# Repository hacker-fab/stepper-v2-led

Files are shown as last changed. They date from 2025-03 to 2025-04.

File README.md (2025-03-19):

# stepper-v2-led
Hacker Fab V2 Stepper UV LED PCB

UV LED module for the [Stepper V2](https://docs.hackerfab.org/home/fab-toolkit/patterning/lithography-stepper-v2-build-work-in-progress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)

Files imported from [Google drive](https://drive.google.com/drive/u/1/folders/1X3nmuruO58prPQBm8DrWUhfM-LNq0qWm)

Supported projectors:
  * DLPDLCR471TPEVM: the classic V2 projector
  * DLP4710EVM-LC: experimental projector due to part shortage

LED compatibility:

| Pin | DLPDLCR471TPEVM | DLP4710EVM-LC |
| --- | --- | --- |
| 10 | N/C | Common |
| 9 | N/C | Common |
| 8 | LED+ | Common |
| 7 | LED+ | Common |
| 6 | LED+ | Common |
| 5 | LED+ | LED1+ |
| 4 | LED- | LED1+ |
| 3 | LED- | LED1+ |
| 2 | LED- | LED2+ |
| 1 | LED- | LED2+ |

"You can order it through your PCB manufacturer of choice (we used JLCPCB). However, note that the PCB is copper core. This is because the LEDs draw several amps of current in operation. To ensure that the PCB doesn't melt, you should use copper core to facilitate better heat flow."

"When ordering the PCB, the manufacturer might send you an email asking about a missing heatsink file. In this case, please respond that this project does not include a direct heatsink, as the copper core PCB itself is designed to handle the thermal management."

DLPDLCR471TPEVM (4 LED) BOM:

| Vendor | Model | Price each (2025) | Quantity | Link |
| --- | --- | --- | --- | --- |
|  	Lumileds |  L1F3-U400200012000  | $10.50 |  4  |  [Digikey](https://www.digikey.com/en/products/detail/lumileds/L1F3-U400200012000/7389568)  |
| Molex  |  0874371043  | $0.71 |  1  |  [Digikey](https://www.digikey.com/en/products/detail/molex/0874371043/717647)  |

Notes:
* DLP4710EVM-LC
  * Instead use [Molex 0874381043](https://www.digikey.com/en/products/detail/molex/0874381043/699154)
  * [FOSSF Silicon notes](https://docs.google.com/document/d/1Yg9_48nFprNLK36mjKuTRpAcMww_u_pMMim5-wJe3lg/edit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)
* Connectors mate with [Molex 0874391000](https://www.digikey.com/en/products/detail/molex/0874391000/561773)
  * Pins: suggest [Molex 874210000](https://www.digikey.com/en/products/detail/molex/0874210000/2037270)

TODO:
* Organize outputs / "history"
  * Which are 4 vs 6 LED designs?
* Create gerber release files
* Port existing files to KiCAD?
* Add images to docs
* DLP4710EVM-LC
  * Measure voltage on existing blue LEDs
    * Are these driven with lower voltage?
  * Make new PCB
  * Clean BOM instructions (connector / LEDs)
link a pr
# History

I can't access the [officially linked gerber file](https://drive.google.com/drive/u/1/folders/1DK4DBdWB0b6NKSaRz9XtcY19dkCHzusb)

FIXME: some files look somewhat identical but not vs the timestamps?

Looks like started with 6 LED design and then moved to 4 LED

| Artifact | Drive name | LEDs | Notes |
| --- | --- | ---  | --- |
| dlpdlcr471tpevm-led_v1.zip | Project Outputs for UV_LED.zip | 6 | "1:49:43 AM On 6/20/2023" |
| dlpdlcr471tpevm-led_v2.zip | Project Outputs for UV_LED (2).zip<br>(Project Outputs for UV_LED/) | 6 | "2:43:13 PM On 6/20/2023"<br>Rounds / enlarges traces |
| dlpdlcr471tpevm-led_v3.zip | UV_LED_v2.zip | 4 | "6:19:09 PM On 10/3/2023"<br>"Official" file in the instructions? |

Note these two were nearly identical:
* "Project Outputs for UV_LED/": lf line endings. Deleted since redundant + inconsistent
* "Project Outputs for UV_LED (2).zip": cr/lf line endings
* Most have cr/lf line endings

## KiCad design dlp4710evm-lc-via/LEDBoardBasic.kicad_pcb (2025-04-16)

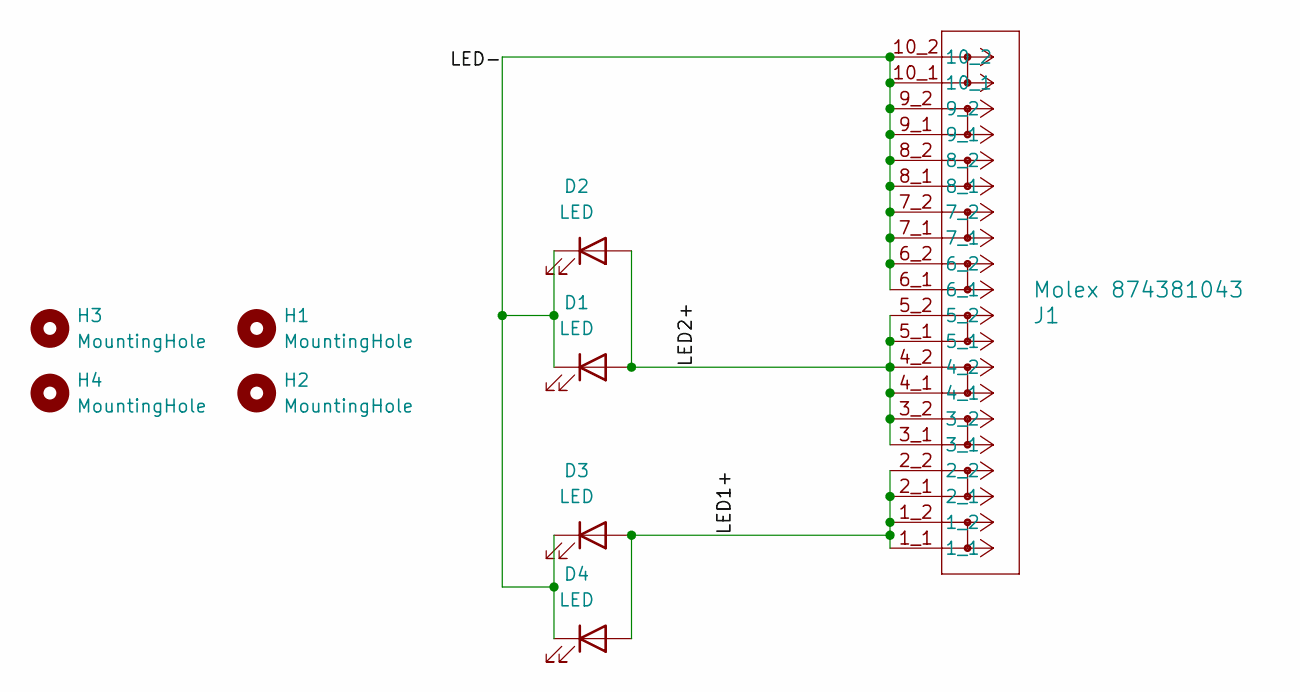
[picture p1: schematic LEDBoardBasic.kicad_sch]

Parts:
D1, D2, D3, D4: LED; LED_Cree-XQ
H1, H2: MountingHole; 0dot093_inch_mechanical_hole
H3, H4: MountingHole; 0dot060_inch_mechanical_hole
J1: Molex 874381043; CONN_874380231-SD_10_MOL

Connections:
/LED1+: D3.2 (A), D4.2 (A), J1.1_1, J1.1_2, J1.2_1, J1.2_2
/LED2+: D1.2 (A), D2.2 (A), J1.3_1, J1.3_2, J1.4_1, J1.4_2, J1.5_1, J1.5_2
/LED-: D1.1 (K), D2.1 (K), D3.1 (K), D4.1 (K), J1.6_1, J1.6_2, J1.7_1, J1.7_2, J1.8_1, J1.8_2, J1.9_1, J1.9_2, J1.10_1, J1.10_2

Board: 2 copper layers, 9 parts (0 on the bottom side), 3 nets, no tracks yet.

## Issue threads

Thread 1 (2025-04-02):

DLP4710EVM-LC support

JohnDMcMaster, 2025-04-02:
Summary:
- Pinout is not identical (not is connector) to the existing projector. This has been documented in the main README in a table
- Some brief hacks were done using the existing PCB and driving it externally. Note: unclear if it fits correctly / this is really messy
- A replacement PCB has been designed. Under review. I'm encouraging the author (Devin) to create a pull request with it. In the meantime I'm going to review it soon

JohnDMcMaster, 2025-04-02:
this was auto closed by the PR but isn't actually done yet

JohnDMcMaster, 2025-04-14:
The above submission was rejected by JLC PCB a bit back. Their notes are below. Next steps:
- Devin might be able to take a look, but in parallel I'm going to review the issues to see if I can resolve it
-

JohnDMcMaster, 2025-04-15:
Unfortunately doesn't seem like they have any example projects

Devin has given me a new project that's a conventional 2 layer board. Reviewing and will send out if it looks passable

JohnDMcMaster, 2025-04-16:
The "via" substitute board has been sent for fab. I'm going to see if we can cancel the copper core order and see how far we get with this one

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

JohnDMcMaster, 2025-04-16:
Devin merged a PR to fix some library warnings

FYI the gerbers for above can be found here: https://github.com/hacker-fab/stepper-v2-led/blob/main/gerber/dlp4710evm-lc-led-via_v1.zip

JohnDMcMaster, 2025-04-26:
Installed. So far working both electrically and mechanically huzzah

Closed 2025-04-26.

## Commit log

2025-03-19 Import files from drive verbatim
    [UV_LED.GBL, UV_LED.GBO, UV_LED.GBP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]
2025-03-19 Organize / normalize file names
    [UV_LED.GBL, UV_LED.GBO, UV_LED.GBP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]
2025-03-19 clean up gerber files
2025-04-02 Added KiCAD Files
    KiCAD files added
    [LEDBoard-B_Cu.gbr, LEDBoard-B_Fab.gbr, LEDBoard-B_Mask.gbr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]
2025-04-02 Removed redundant files
    Removed redundant files
    [LEDBoardUnhaunted-B_Cu.gbr, LEDBoardUnhaunted-B_Fab.gbr, LEDBoardUnhaunted-B_Mask.gbr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]
2025-04-08 clean up new projector file name
    [LEDBoard-B_Cu.gbr, LEDBoard-B_Fab.gbr, LEDBoard-B_Mask.gbr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]
2025-04-08 dlp4710evm-lc-led: clean up / normalize outputs
    [LEDBoard-B_Cu.gbr, LEDBoard-B_Fab.gbr, LEDBoard-B_Mask.gbr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]
2025-04-15 Added LEDBoardBasic Files
    An alternative board is now available, titled LEDBoardBasic, which achieves the LED heatsinking through many vias to the back copper of a standard 2 sided FR4 core board
    [LEDBoardBasic-B_Cu.gbr, LEDBoardBasic-B_Mask.gbr, LEDBoardBasic-B_Paste.gbr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]
2025-04-15 normalize file names
    [LEDBoardBasic-B_Cu.gbr, LEDBoardBasic-B_Mask.gbr, LEDBoardBasic-B_Paste.gbr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]
2025-04-16 dlp4710evm-lc-via_v1 release candidate
    [LEDBoardBasic.kicad_pcb, LEDBoardBasic.kicad_sch]
2025-04-16 dlp4710evm-lc-via: tweak inconsistent solder mask
    [LEDBoardBasic.kicad_pcb]
2025-04-16 Added footprints
    Added mechanical hole footprints which were missing from project library.
    [LEDBoardBasic.kicad_pcb, LEDBoardBasic.kicad_sch]
2025-04-16 gerber: fix file name
